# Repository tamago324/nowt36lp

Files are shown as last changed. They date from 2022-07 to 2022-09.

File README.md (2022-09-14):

# nowt36lp

horizon プラグインを使ってボトムプレートとトッププレートを生成した

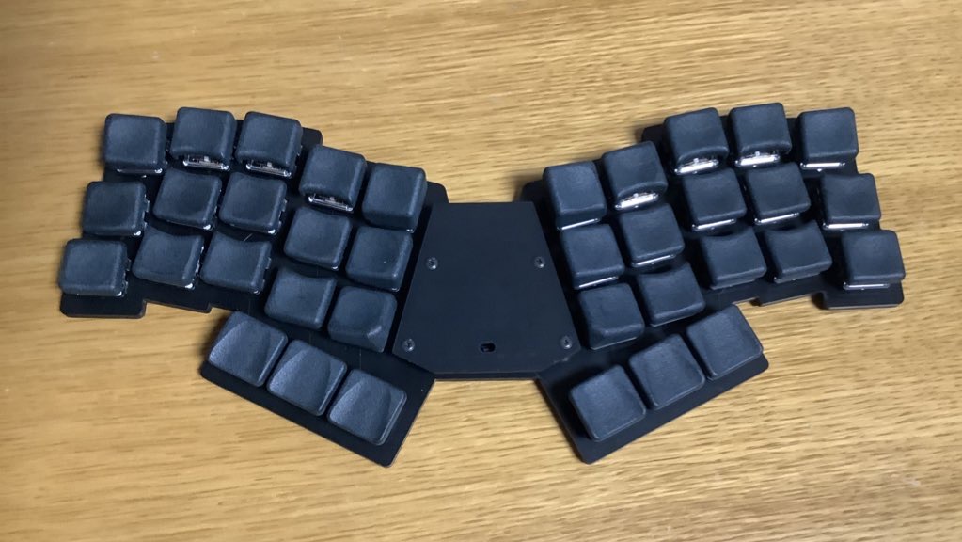
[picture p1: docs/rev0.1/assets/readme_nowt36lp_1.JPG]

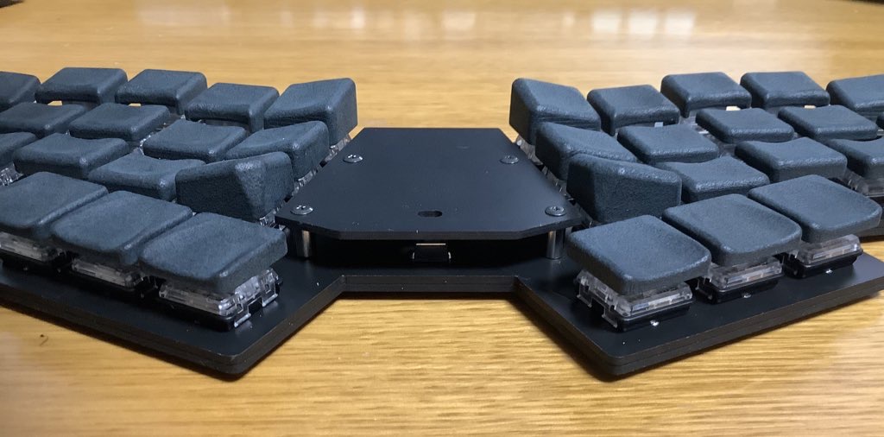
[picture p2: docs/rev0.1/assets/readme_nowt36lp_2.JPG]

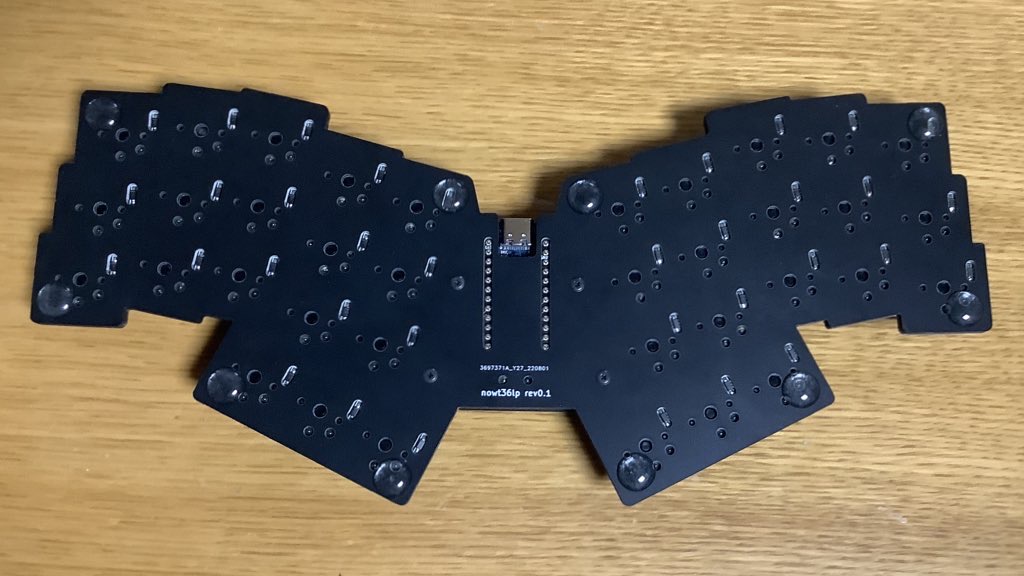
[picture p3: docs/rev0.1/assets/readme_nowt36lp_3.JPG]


## LICENSE

<br />この 作品 は <a rel="license" href="http://creativecommons.org/licenses/by/4.0/">クリエイティブ・コモンズ 表示 4.0 国際 ライセンス</a>の下に提供されています。

> 帰属—適切なクレジットを表示し、ライセンスへのリンクを提供し、変更が行われたかどうかを示す必要があります。

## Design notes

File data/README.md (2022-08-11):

# nowt36lp

## 発注するためのデータの作り方

1. (horizon プラグイン)[https://github.com/skarrmann/horizon]を KiCAD に入れる
2. `revX` (`rev0.1` や `rev0.2` など) 内の `pcb/nowt36lp.kicad_pcb` を開く
3. horizon プラグインを使って、発注するためのデータを作成する

## horizon プラグインの使い方

### もととなるKiCADのデータの作成方法

ボトムプレートとトッププレートを生成するためのデータはレイヤごとに作成されます

* `F.Adhesive` レイヤ：トッププレートの穴とEdge.Cuts
* `B.Adhesive` レイヤ：ボトムプレートの穴とEdge.Cuts

### horizon プラグインを使用して、ボトムプレートとトッププレートのデータを生成する

PCBエディタを開き、ツール > 外部プラグイン > Horizon Board Productor を実行する。

正しく実行できた場合、`data/` ディレクトリに `temp` と `gerbers` が生成される。

`temp` は KiCAD プロジェクトで、`gerbers` は JLCPCB (のみ？) に発注できるデータ。

`temp` を修正し、ガーバーファイルを生成して、発注することも可能

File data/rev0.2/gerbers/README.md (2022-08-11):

rev0.2 の発注用

2022/08/12 に発注し、まだ確認していないがおそらく問題ないと思われる

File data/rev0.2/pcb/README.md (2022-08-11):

## 発注するデータの作成方法

horizon のプラグインを使って、発注するためのデータを作成

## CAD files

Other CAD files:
data/rev0.2/nowt36.FCStd

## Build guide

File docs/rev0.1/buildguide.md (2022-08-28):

# nowt36lp ビルドガイド

nowt36lp rev0.1 のビルドガイドです。

<details><summary>目次</summary><div>

<!-- vim-markdown-toc GFM -->

* [キットに含まれるもの](#キットに含まれるもの)
* [キット以外に必要なもの](#キット以外に必要なもの)
* [組み立て順序の確認](#組み立て順序の確認)
* [組み立て](#組み立て)
  * [1. ファームウェアの書き込み](#1-ファームウェアの書き込み)
    * [Remap で書き込む場合](#remap-で書き込む場合)
  * [2. (オプション) プレートの側面をペンで塗る](#2-オプション-プレートの側面をペンで塗る)
  * [3. ダイオードのはんだ付け](#3-ダイオードのはんだ付け)
  * [4. スイッチのはんだ付け](#4-スイッチのはんだ付け)
  * [5. リセットスイッチのはんだ付け](#5-リセットスイッチのはんだ付け)
  * [6. ボトムプレートを取り付ける](#6-ボトムプレートを取り付ける)
  * [7. ProMicro保護プレートを取り付ける](#7-promicro保護プレートを取り付ける)
  * [8. ゴム足を取り付ける](#8-ゴム足を取り付ける)
  * [9. キーキャップを取り付ける](#9-キーキャップを取り付ける)
  * [10.キーマップを変更する](#10キーマップを変更する)
* [最後に](#最後に)

<!-- vim-markdown-toc -->

</div></details>

## キットに含まれるもの

| No. | 名前 | 数量 | 備考 |
|-----|---|---|---|
| 1 | PCB | 1枚 | メインPCB |
| 2 | ボトムプレート | 1枚 | ボトムアクリルプレート |
| 3 | ProMicro 保護プレート | 1枚 | ProMicro 保護プレート。 |
| 4 | リセットスイッチ | 1個 | タクトスイッチ。<br>[遊舎工房](https://shop.yushakobo.jp/collections/all-keyboard-parts/products/a0800ts-01-1?variant=37665574977697)で購入できます。 |
| 5 | ダイオード | 36個 + 予備 | [遊舎工房](https://shop.yushakobo.jp/collections/all-keyboard-parts/products/a0800di-02-100)で購入できます。 |
| 6 | M2 スペーサー 8mm | 4個 | ProMicro保護プレートとボトムプレートを固定するためのスペーサー。<br>[ヒロスギネット](https://www.hirosugi-net.co.jp/shop/c/c10141012/)で購入できます。 |
| 7 | M2 ねじ 5mm | 8個 | スペーサーを固定するネジ。<br>[モノタロウ](https://www.monotaro.com/p/4307/6774/)で購入できます。 |
| 8 | ゴム足 | 10個 | すべり止め用のゴム足。<br>[Amazon](https://www.amazon.co.jp/gp/product/B01B4COI8W/ref=ppx_yo_dt_b_asin_title_o07_s00?ie=UTF8&psc=1)で購入できます。 |
| 9 | 両面テープ (5mm幅) | - | PCBとボトムプレートを張り合わせるために使用。 <br>[Amazon](https://www.amazon.co.jp/gp/product/B00VFSHS1K/ref=ppx_yo_dt_b_asin_title_o02_s00?ie=UTF8&psc=1)で購入できます。 |

## キット以外に必要なもの

| 名前 | 数量 | 備考 |
|---|---|---|
| キースイッチ | 36個 | choc用のキーキャップ |
| キーキャップ | 36個 | chocスイッチ |
| USBケーブル | 1個  | ProMicroに合ったもの |
| ProMicro | 1個  | - |
| コンスルー or ピンヘッダ | 2枚  | - |

## 組み立て順序の確認

1. ファームウェアの書き込み
2. (オプション) プレートの側面をペンで塗る
3. ダイオードのはんだ付け
4. スイッチのはんだ付け
5. リセットスイッチのはんだ付け
6. ボトムプレートを取り付ける
7. ProMicro保護プレートを取り付ける
8. ゴム足を取り付ける
9. キーキャップを取り付ける
10. キーマップを変更する

## 組み立て

### 1. ファームウェアの書き込み

QMK を使用して、ファームウェアを書き込みます。

ファアームウェアは[こちら](https://github.com/tamago324/qmk_firmware/tree/nowt36/keyboards/tamago324/nowt36lp)

<details><summary>Remap で書き込む場合</summary><div>

#### Remap で書き込む場合

> サリチル酸さんの[記事](https://salicylic-acid3.hatenablog.com/entry/remap-manual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,%E3%83%95%E3%82%A1%E3%83%BC%E3%83%A0%E3%82%A6%E3%82%A7%E3%82%A2%E3%82%92%E6%9B%B8%E3%81%8D%E8%BE%BC%E3%82%80,-%E3%82%AD%E3%83%BC%E3%83%9C%E3%83%BC%E3%83%89%E3%82%AB%E3%82%BF%E3%83%AD%E3%82%B0%E6%A9%9F%E8%83%BD)を参考に手順を記述しています。

https://remap-keys.app/ にアクセスします。 

KEYBOARD CATALOG をクリックします。

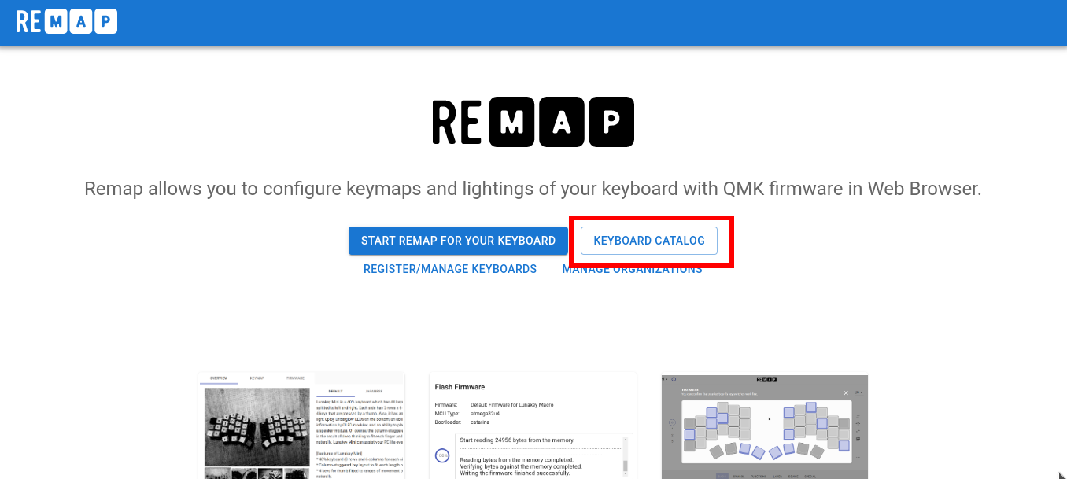
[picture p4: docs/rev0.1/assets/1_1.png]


Keyboard name の入力欄に `nowt36lp` と入力し、Search をクリックし、検索結果の nowt36lp をクリックします。

TODO

FIRMWARE をクリックします。

TODO

FLASH をクリック

TOOD

ダイアログが表示されたら FLASH をクリックします。



remap-keys.app がシリアルポートへの接続を要求しています という表示が出たら、ピンセットでProMicro の`GND`と`RST`を2回素早く押します。



ProMicro が表示されたら、それを選択し、接続ボタンをクリックします。  



少し時間が立つとファームウェアの書き込みが完了します。

TODO

</div></details>

### 2. (オプション) プレートの側面をペンで塗る

PCB と ボトムプレートの側面をペンで塗るときれいに仕上げられます。

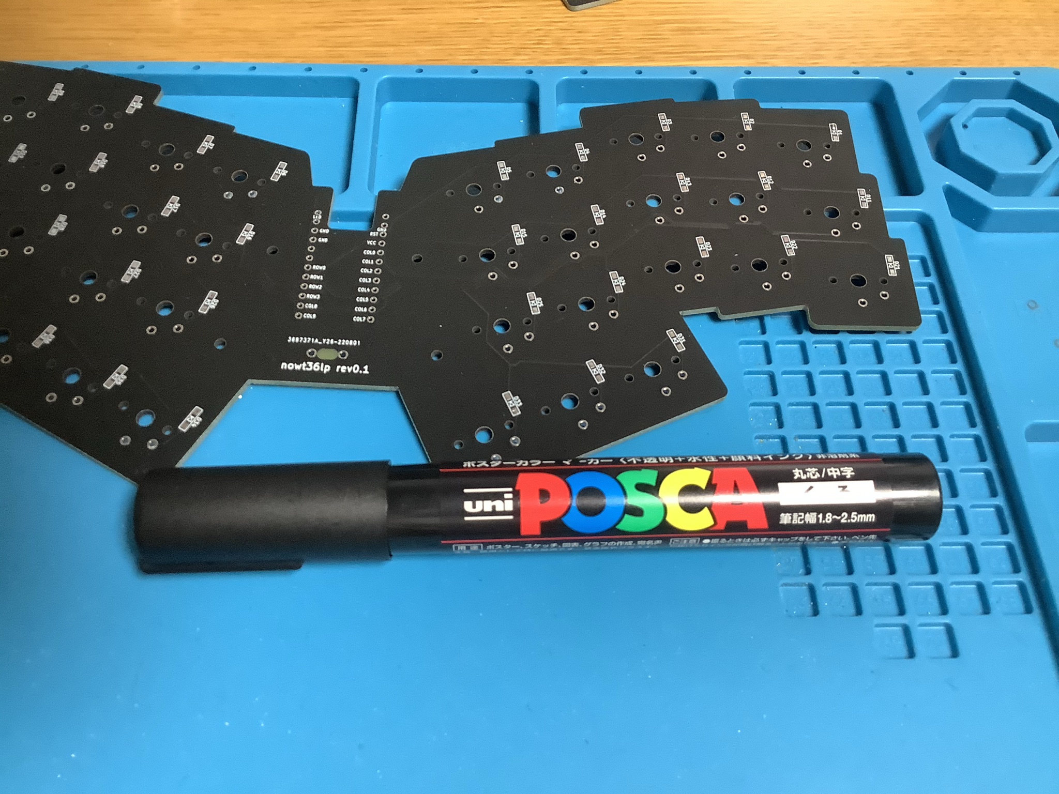
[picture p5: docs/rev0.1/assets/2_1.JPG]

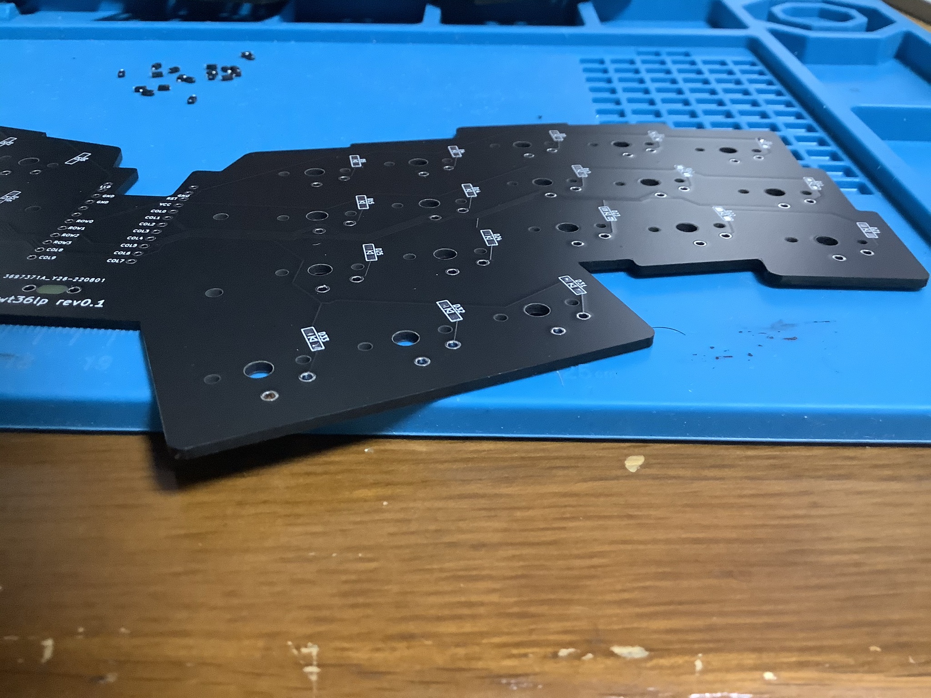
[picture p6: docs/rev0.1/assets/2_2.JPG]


### 3. ダイオードのはんだ付け

PCBの裏にダイオードを36個はんだ付けします。
「PCBのシルクの線」と「ダイオードの線」が一致するようにはんだ付けします。
はんだごての温度は320℃くらいに設定し作業します。

片側に予備ハンダを行い、
ピンセットを使用して、はんだ付けを行い、
もう片方もはんだ付けします。

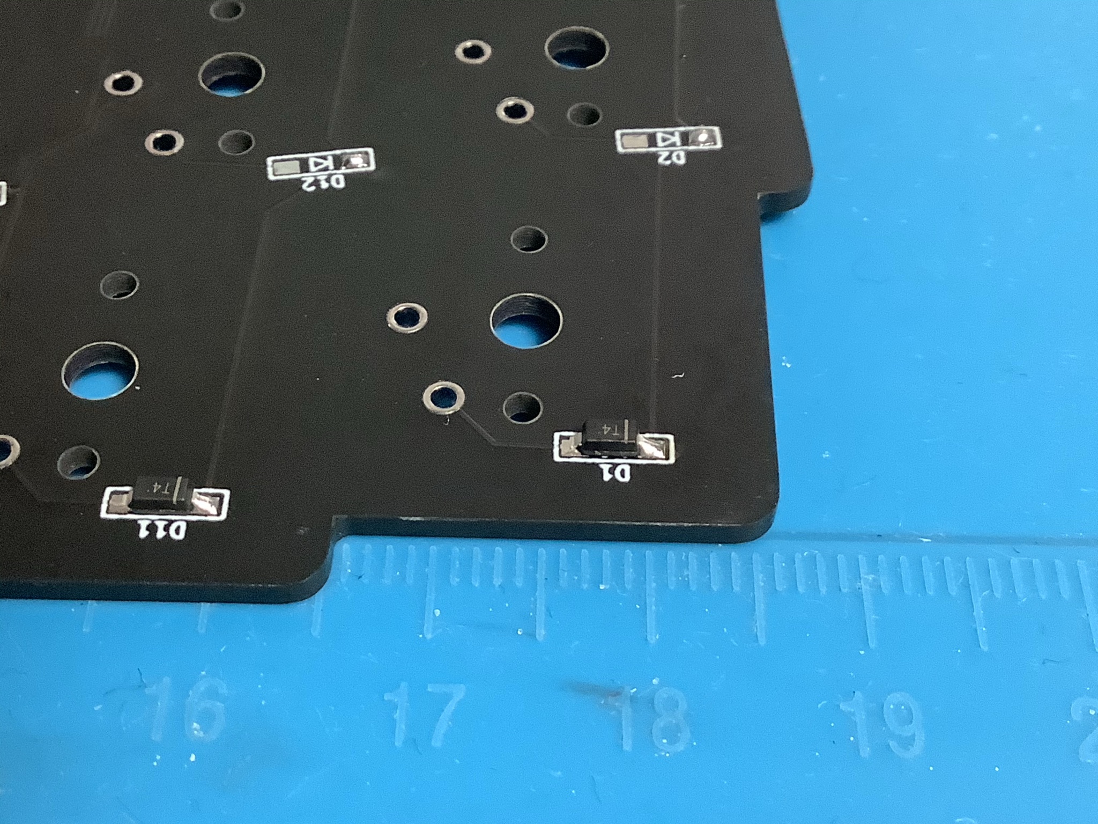
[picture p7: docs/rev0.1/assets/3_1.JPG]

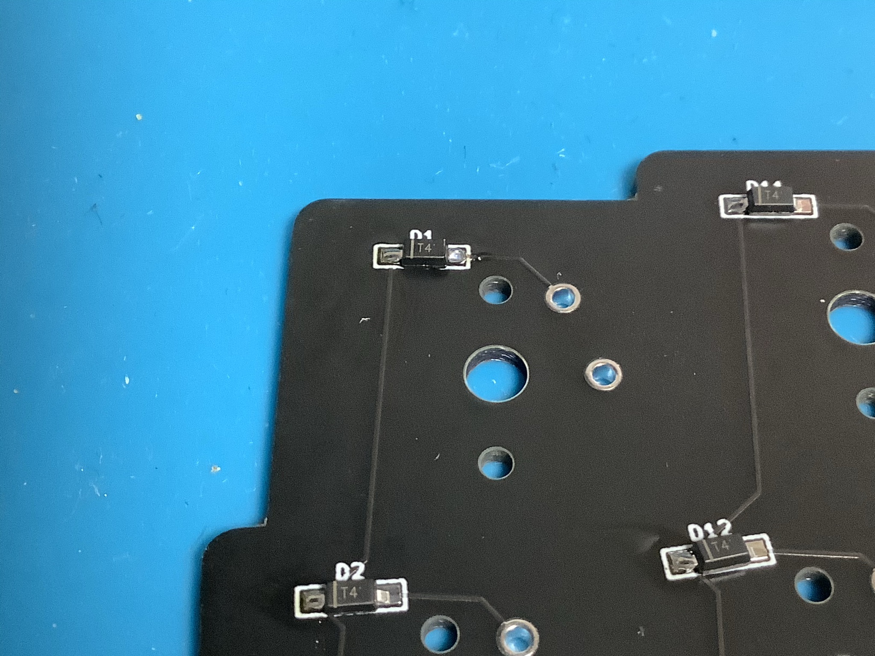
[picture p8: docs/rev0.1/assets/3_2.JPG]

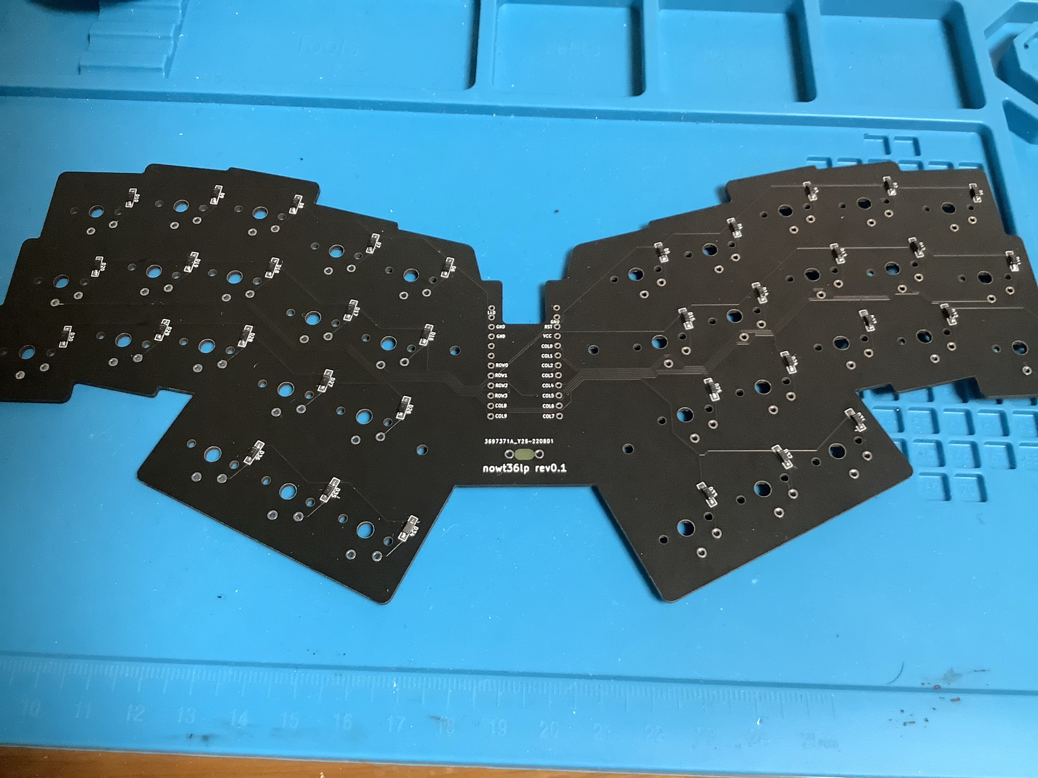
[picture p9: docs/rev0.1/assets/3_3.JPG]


すべてのダイオードのはんだ付けが終わったら、すべてのダイオードが同じ向きになっていることを確認してください。

### 4. スイッチのはんだ付け

PCBの表からスイッチを差し込み、裏からスイッチをはんだ付けします。
はんだごての温度は320℃くらいに設定し作業します。

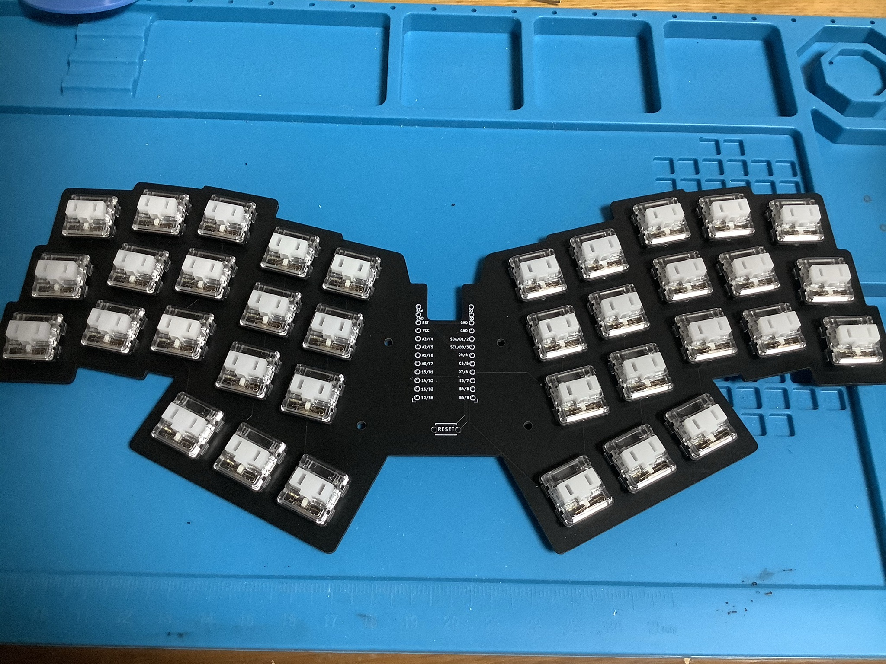
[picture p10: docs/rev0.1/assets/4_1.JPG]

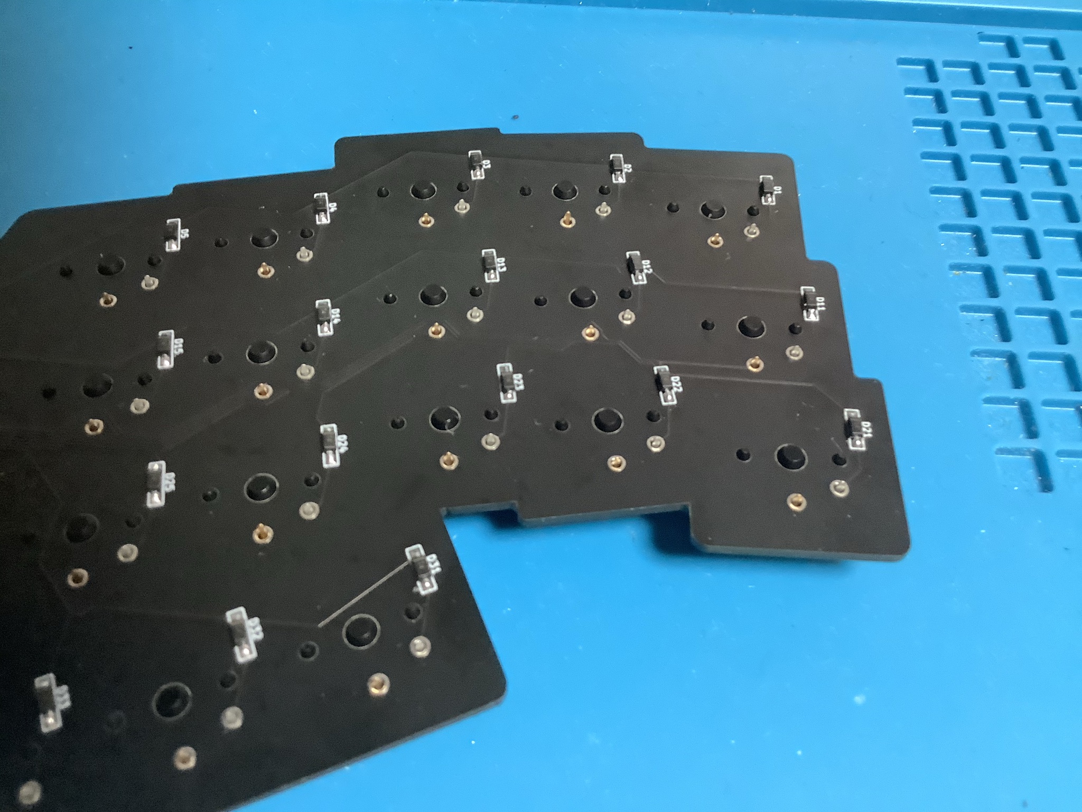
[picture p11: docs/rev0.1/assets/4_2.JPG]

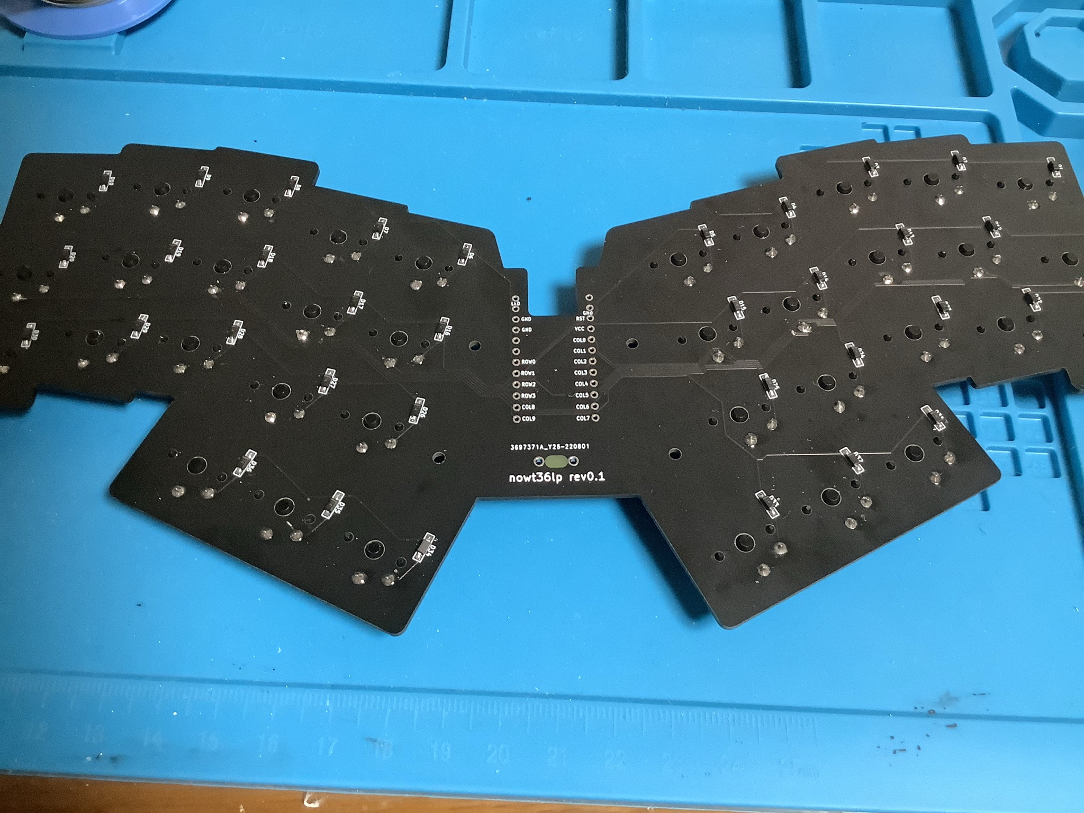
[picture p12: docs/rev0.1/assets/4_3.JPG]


### 5. リセットスイッチのはんだ付け

PCBの表から RESET という文字が隠れるようにリセットスイッチを差し込みます。
PCBの裏に出ている足をはんだ付けします。

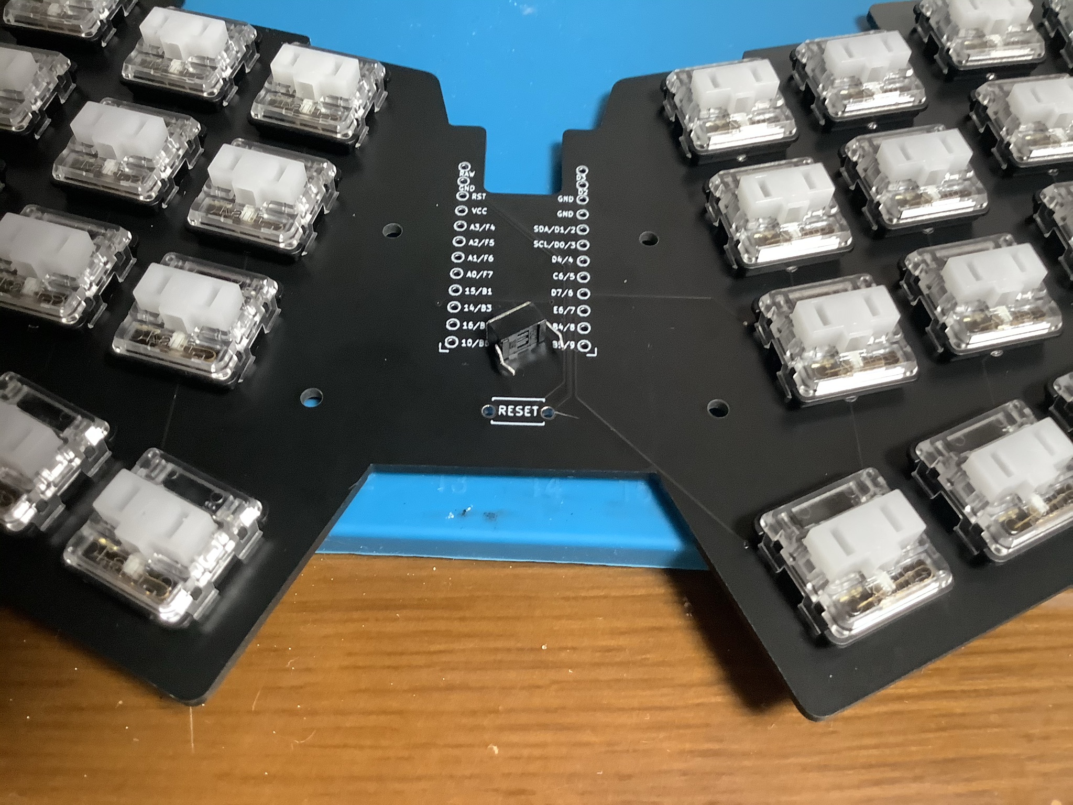
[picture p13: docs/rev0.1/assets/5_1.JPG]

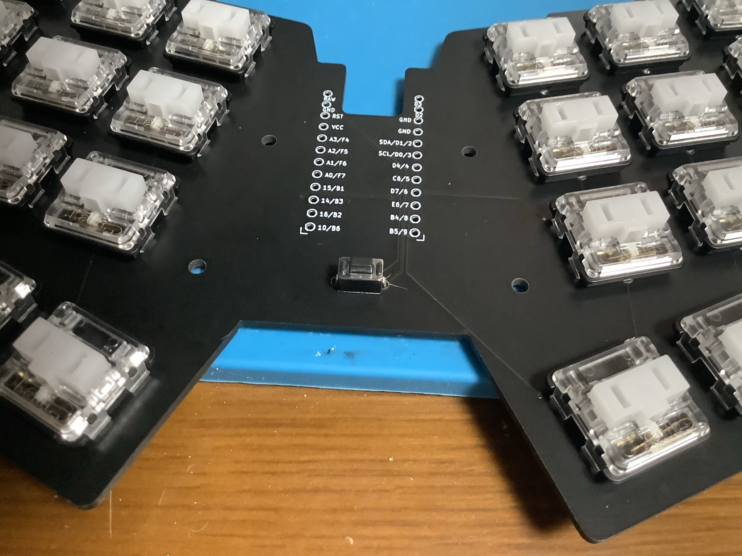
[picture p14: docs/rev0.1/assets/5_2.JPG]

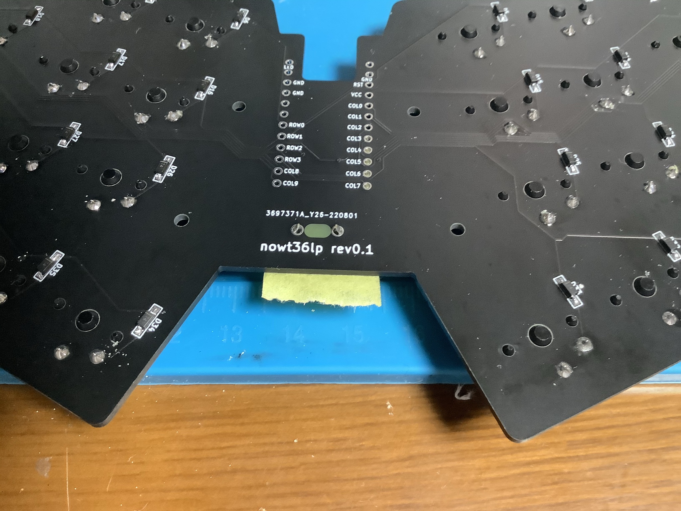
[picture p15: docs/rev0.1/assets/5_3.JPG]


### 6. ボトムプレートを取り付ける

両面テープをPCBに貼り付け、ボトムプレートがずれないように貼り付けます。

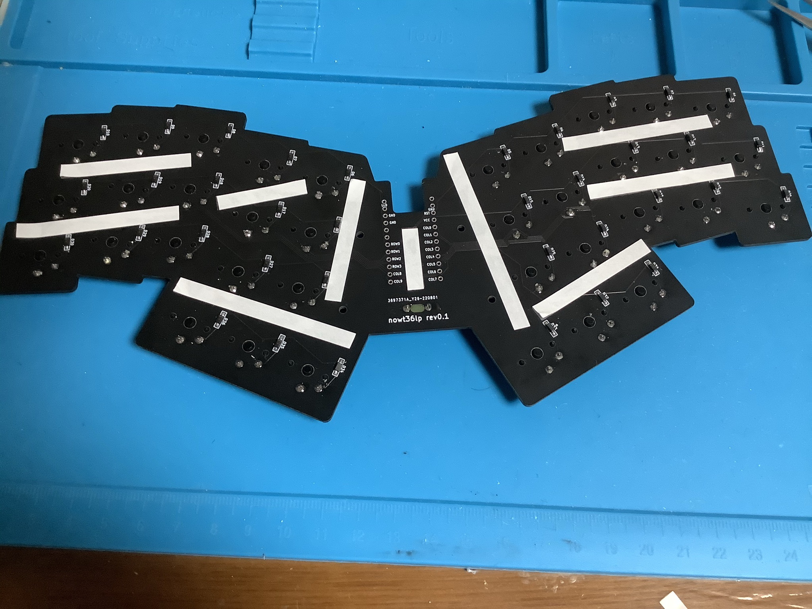
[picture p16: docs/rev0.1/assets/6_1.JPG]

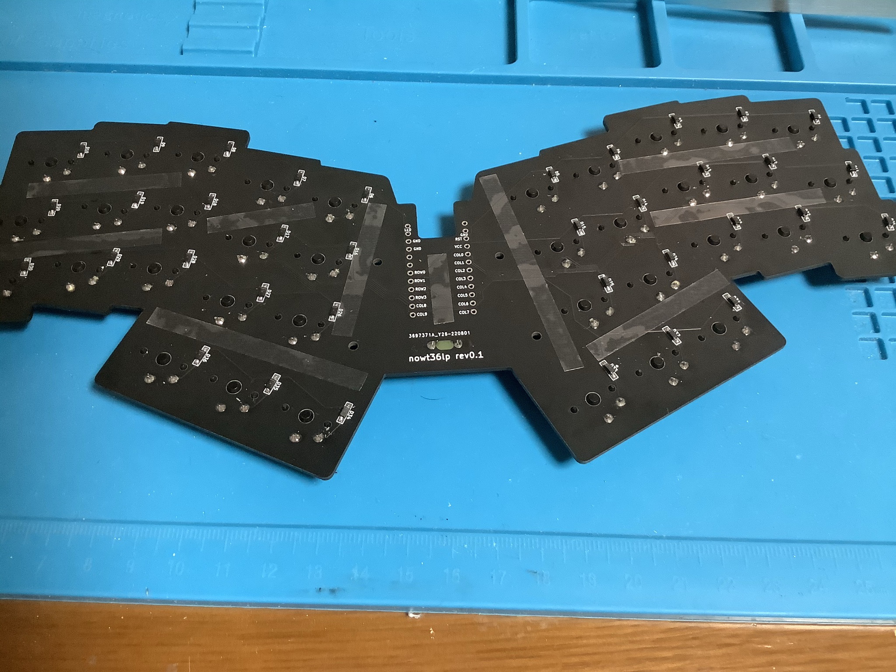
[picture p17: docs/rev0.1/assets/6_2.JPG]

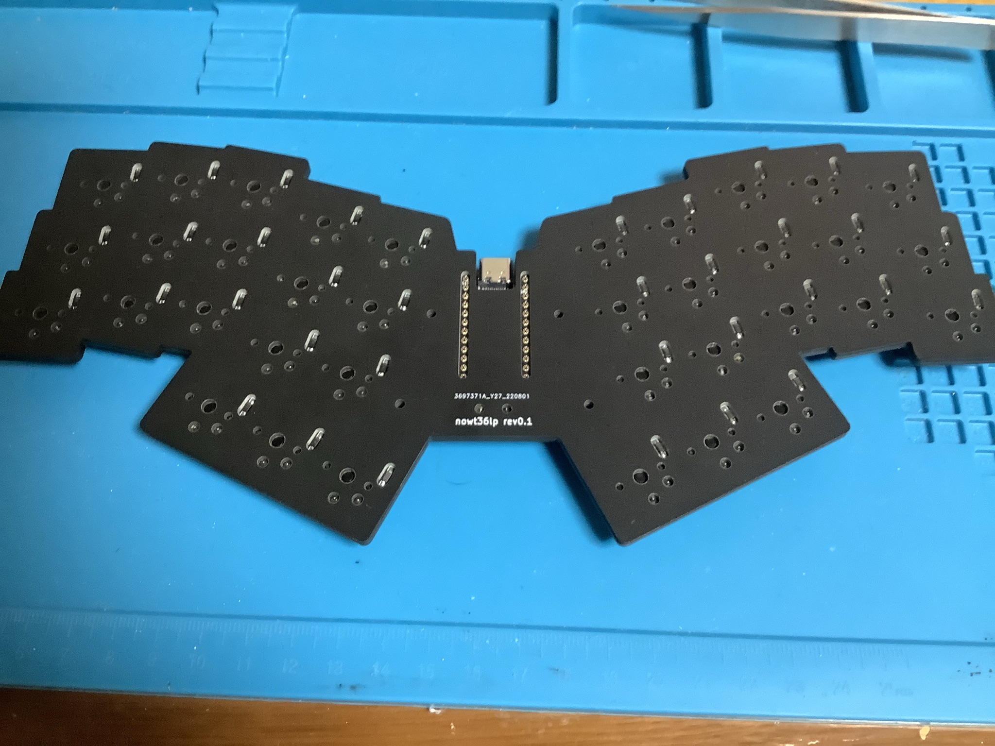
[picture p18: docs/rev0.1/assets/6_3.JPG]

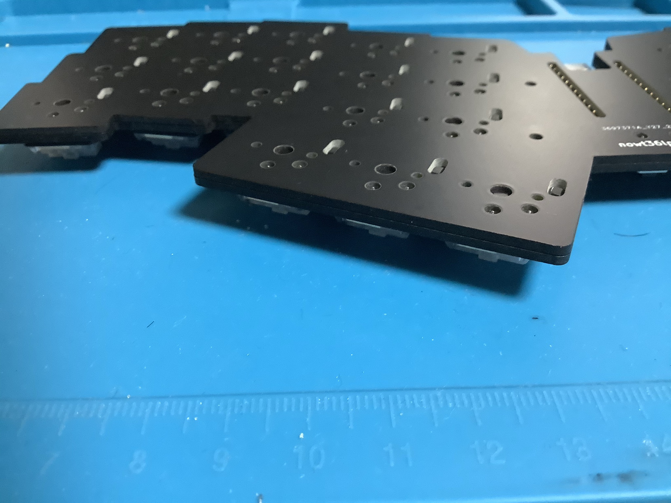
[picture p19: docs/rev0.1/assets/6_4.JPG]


### 7. ProMicro保護プレートを取り付ける

ボトムプレートのうらから、ネジでスペーサーを固定し、ProMicro保護プレートをねじ止めします。

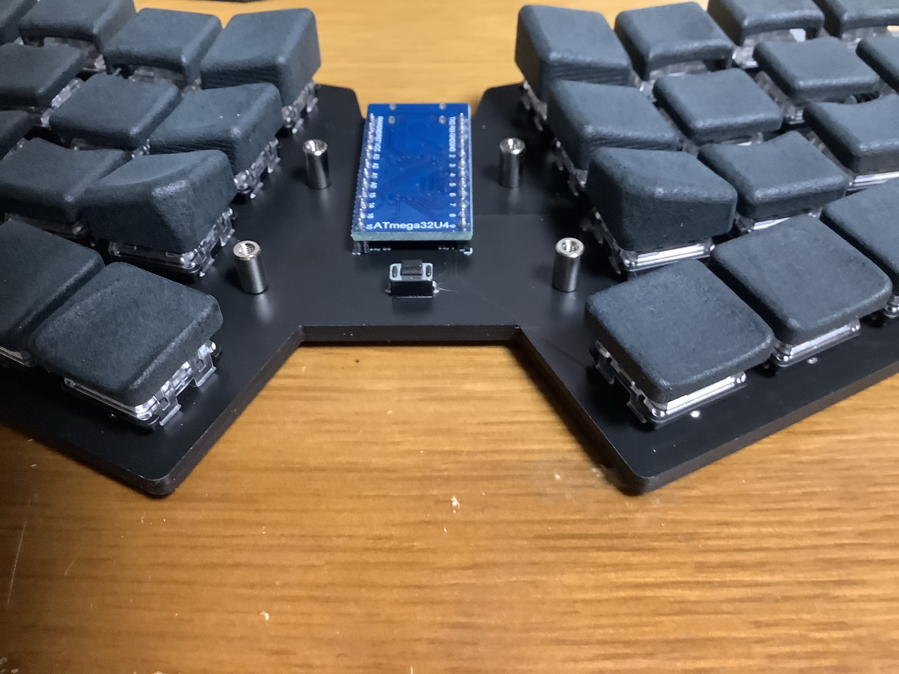
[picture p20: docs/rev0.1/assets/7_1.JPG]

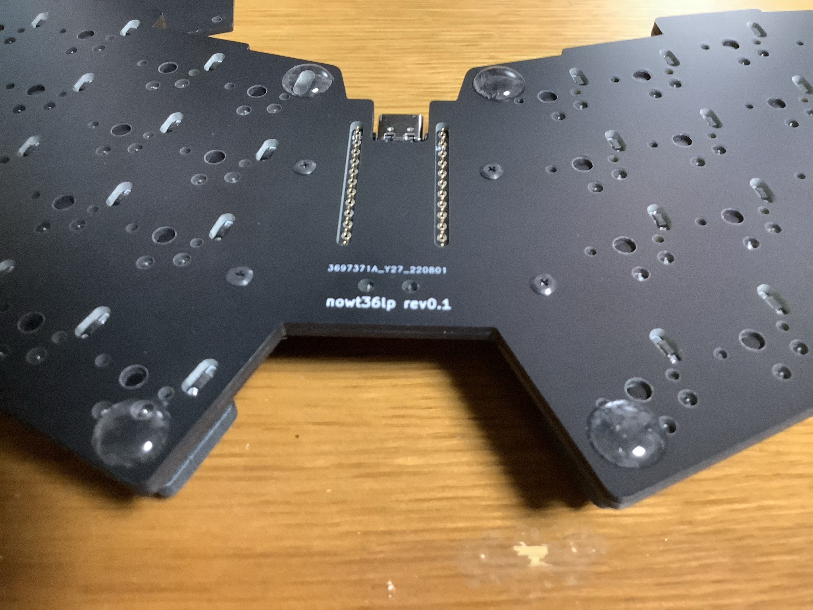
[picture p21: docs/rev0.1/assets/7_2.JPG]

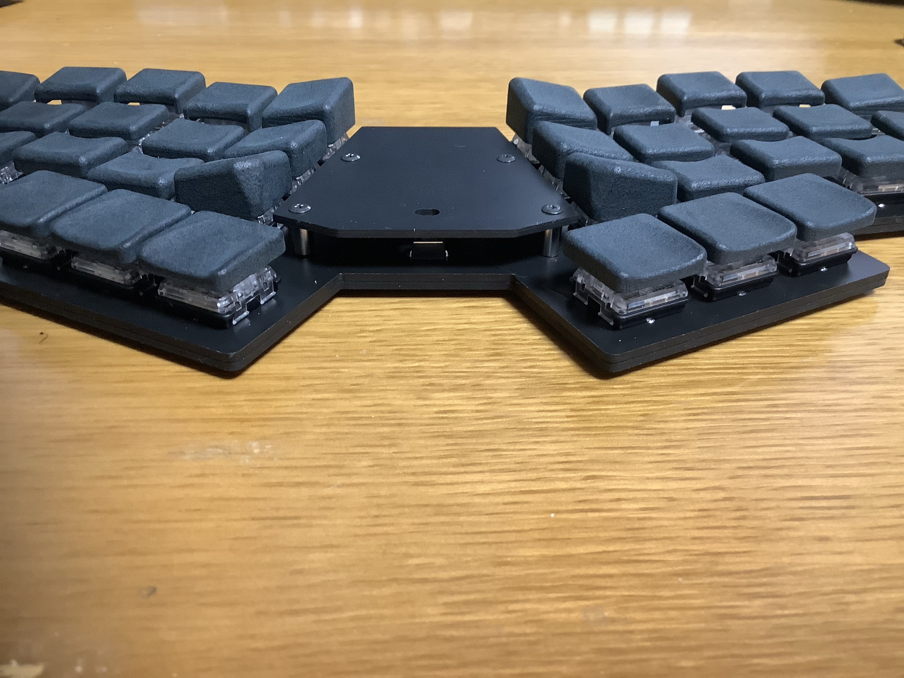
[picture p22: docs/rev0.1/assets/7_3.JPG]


### 8. ゴム足を取り付ける

ボトムプレートの裏にゴム足をつけます。



### 9. キーキャップを取り付ける

キーキャップを取り付けます。



### 10.キーマップを変更する

Remap か QMK を使用してキーマップを変更可能です。

* Remap の場合: キーボードカタログの nowt36lp のページで設定可能です。
* QMK の場合: [tamago324/qmk_firmware](https://github.com/tamago324/qmk_firmware/tree/nowt36) の `nowt36` ブランチの `keyboards/tamago324/nowt36lp` にファームウェアがあります。

## 最後に

完成したキーボードの写真を SNS に投稿していただけるととても嬉しいです！
(ハッシュタグは `#nowt36lp` です。)

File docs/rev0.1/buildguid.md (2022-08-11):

# nowt36lp ビルドガイド

nowt36lp rev0.1 のビルドガイドです。

<details><summary>目次</summary><div>

<!-- vim-markdown-toc GFM -->

* [キットに含まれるもの](#キットに含まれるもの)
* [キット以外に必要なもの](#キット以外に必要なもの)
* [組み立て順序の確認](#組み立て順序の確認)
* [組み立て](#組み立て)
  * [1. ファームウェアの書き込み](#1-ファームウェアの書き込み)
  * [2. (オプション) プレートの側面をペンで塗る](#2-オプション-プレートの側面をペンで塗る)
  * [3. ダイオードのはんだ付け](#3-ダイオードのはんだ付け)
  * [4. スイッチのはんだ付け](#4-スイッチのはんだ付け)
  * [5. リセットスイッチのはんだ付け](#5-リセットスイッチのはんだ付け)
  * [6. ボトムプレートを取り付ける](#6-ボトムプレートを取り付ける)
  * [7. ProMicro保護プレートを取り付ける](#7-promicro保護プレートを取り付ける)
  * [8. ゴム足を取り付ける](#8-ゴム足を取り付ける)
  * [9. キーキャップを取り付ける](#9-キーキャップを取り付ける)
* [最後に](#最後に)

<!-- vim-markdown-toc -->

</div></details>

## キットに含まれるもの

| No. | 名前 | 数量 | 備考 |
|-----|---|---|---|
| 1 | PCB | 1枚  | メインPCB |
| 2 | ボトムプレート | 1枚  | ボトムアクリルプレート |
| 3 | ProMicro 保護プレート | 1枚  | ProMicro 保護プレート。 |
| 4 | リセットスイッチ | 1個  | タクトスイッチ。<br>[遊舎工房](https://shop.yushakobo.jp/collections/all-keyboard-parts/products/a0800ts-01-1?variant=37665574977697)で購入できます。 |
| 5 | M2 スペーサー 7mm | 4個  | ProMicro保護プレートとボトムプレートを固定するためのスペーサー。<br>[ヒロスギネット](https://www.hirosugi-net.co.jp/shop/c/c10141012/)で購入できます。 |
| 6 | M2 ねじ 5mm | 8個  | スペーサーを固定するネジ。<br>[モノタロウ](https://www.monotaro.com/p/4307/6774/)で購入できます。 |
| 7 | ゴム足 | 10個 | すべり止め用のゴム足。<br>[Amazon](https://www.amazon.co.jp/gp/product/B01B4COI8W/ref=ppx_yo_dt_b_asin_title_o07_s00?ie=UTF8&psc=1)で購入できます。 |
| 8 | 両面テープ (5mm幅) | - | PCBとボトムプレートを張り合わせるために使用。 <br>[Amazon](https://www.amazon.co.jp/gp/product/B00VFSHS1K/ref=ppx_yo_dt_b_asin_title_o02_s00?ie=UTF8&psc=1)で購入できます。 |

## キット以外に必要なもの

| 名前 | 数量 | 備考 |
|---|---|---|
| キースイッチ | 36個 | choc用のキーキャップ |
| キーキャップ | 36個 | chocスイッチ |
| USBケーブル | 1個  | ProMicroに合ったもの |
| ProMicro | 1個  | - |
| コンスルー or ピンヘッダ | 2枚  | - |

## 組み立て順序の確認

1. ファームウェアの書き込み
2. (オプション) プレートの側面をペンで塗る
3. ダイオードのはんだ付け
4. スイッチのはんだ付け
5. リセットスイッチのはんだ付け
6. ボトムプレートを取り付ける
7. ProMicro保護プレートを取り付ける
8. ゴム足を取り付ける
9. キーキャップを取り付ける

## 組み立て

### 1. ファームウェアの書き込み

[QMK](https://github.com/tamago324/qmk_firmware/tree/nowt36/keyboards/nowt36) を使用して、ファームウェアを書き込みます。

> TODO: REMAP での書き込みに対応する

### 2. (オプション) プレートの側面をペンで塗る

PCB と ボトムプレートの側面をペンで塗るときれいに仕上げられます。




### 3. ダイオードのはんだ付け

PCBの裏にダイオードを36個はんだ付けします。
「PCBのシルクの線」と「ダイオードの線」が一致するようにはんだ付けします。
はんだごての温度は320℃くらいに設定し作業します。

片側に予備ハンダを行い、
ピンセットを使用して、はんだ付けを行い、
もう片方もはんだ付けします。





すべてのダイオードのはんだ付けが終わったら、すべてのダイオードが同じ向きになっていることを確認してください。

### 4. スイッチのはんだ付け

PCBの表からスイッチを差し込み、裏からスイッチをはんだ付けします。
はんだごての温度は320℃くらいに設定し作業します。





### 5. リセットスイッチのはんだ付け

PCBの表から RESET という文字が隠れるようにリセットスイッチを差し込みます。
PCBの裏に出ている足をはんだ付けします。





### 6. ボトムプレートを取り付ける

両面テープをPCBに貼り付け、ボトムプレートがずれないように貼り付けます。






### 7. ProMicro保護プレートを取り付ける

ボトムプレートのうらから、ネジでスペーサーを固定し、ProMicro保護プレートをねじ止めします。





### 8. ゴム足を取り付ける

ボトムプレートの裏にゴム足をつけます。



### 9. キーキャップを取り付ける

キーキャップを取り付けます。



## 最後に

完成したキーボードの写真を SNS に投稿していただけるととても嬉しいです！
(ハッシュタグは `#nowt36lp` です。)

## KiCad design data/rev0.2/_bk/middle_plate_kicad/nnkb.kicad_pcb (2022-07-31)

Board: 2 copper layers, 48 parts (0 on the bottom side), 10 nets, no tracks yet.

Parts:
D37, D38, D39, D40, D41, D42, D43, D44, D45, D46: WS2812B; LED_WS2812B_PLCC4_5.0x5.0mm_P3.2mm_middle
SW1, SW2, SW3, SW4, SW5, SW6, SW7, SW8, SW9, SW10, SW11, SW12, SW13, SW14, SW15, SW16, SW17, SW18, SW19, SW20, SW21, SW22, SW23, SW24, SW25, SW26, SW27, SW28, SW29, SW30, SW31, SW32, SW33, SW34, SW35, SW36: SW_PUSH; CherryMX_Hotswap_middle
SW37: RESET_SWITCH; ResetSW_1side_back_middle
U1: ProMicro; ProMicro_v3.5_mods_middle

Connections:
col0: SW1.1, SW11.1, SW21.1
col1: SW2.1, SW12.1, SW22.1
col2: SW3.1, SW13.1, SW23.1, SW31.1
col3: SW4.1, SW14.1, SW24.1, SW32.1
col4: SW5.1, SW15.1, SW25.1, SW33.1
col5: SW6.1, SW16.1, SW26.1, SW34.1
col6: SW7.1, SW17.1, SW27.1, SW35.1
col7: SW8.1, SW18.1, SW28.1, SW36.1
col8: SW9.1, SW19.1, SW29.1
col9: SW10.1, SW20.1, SW30.1

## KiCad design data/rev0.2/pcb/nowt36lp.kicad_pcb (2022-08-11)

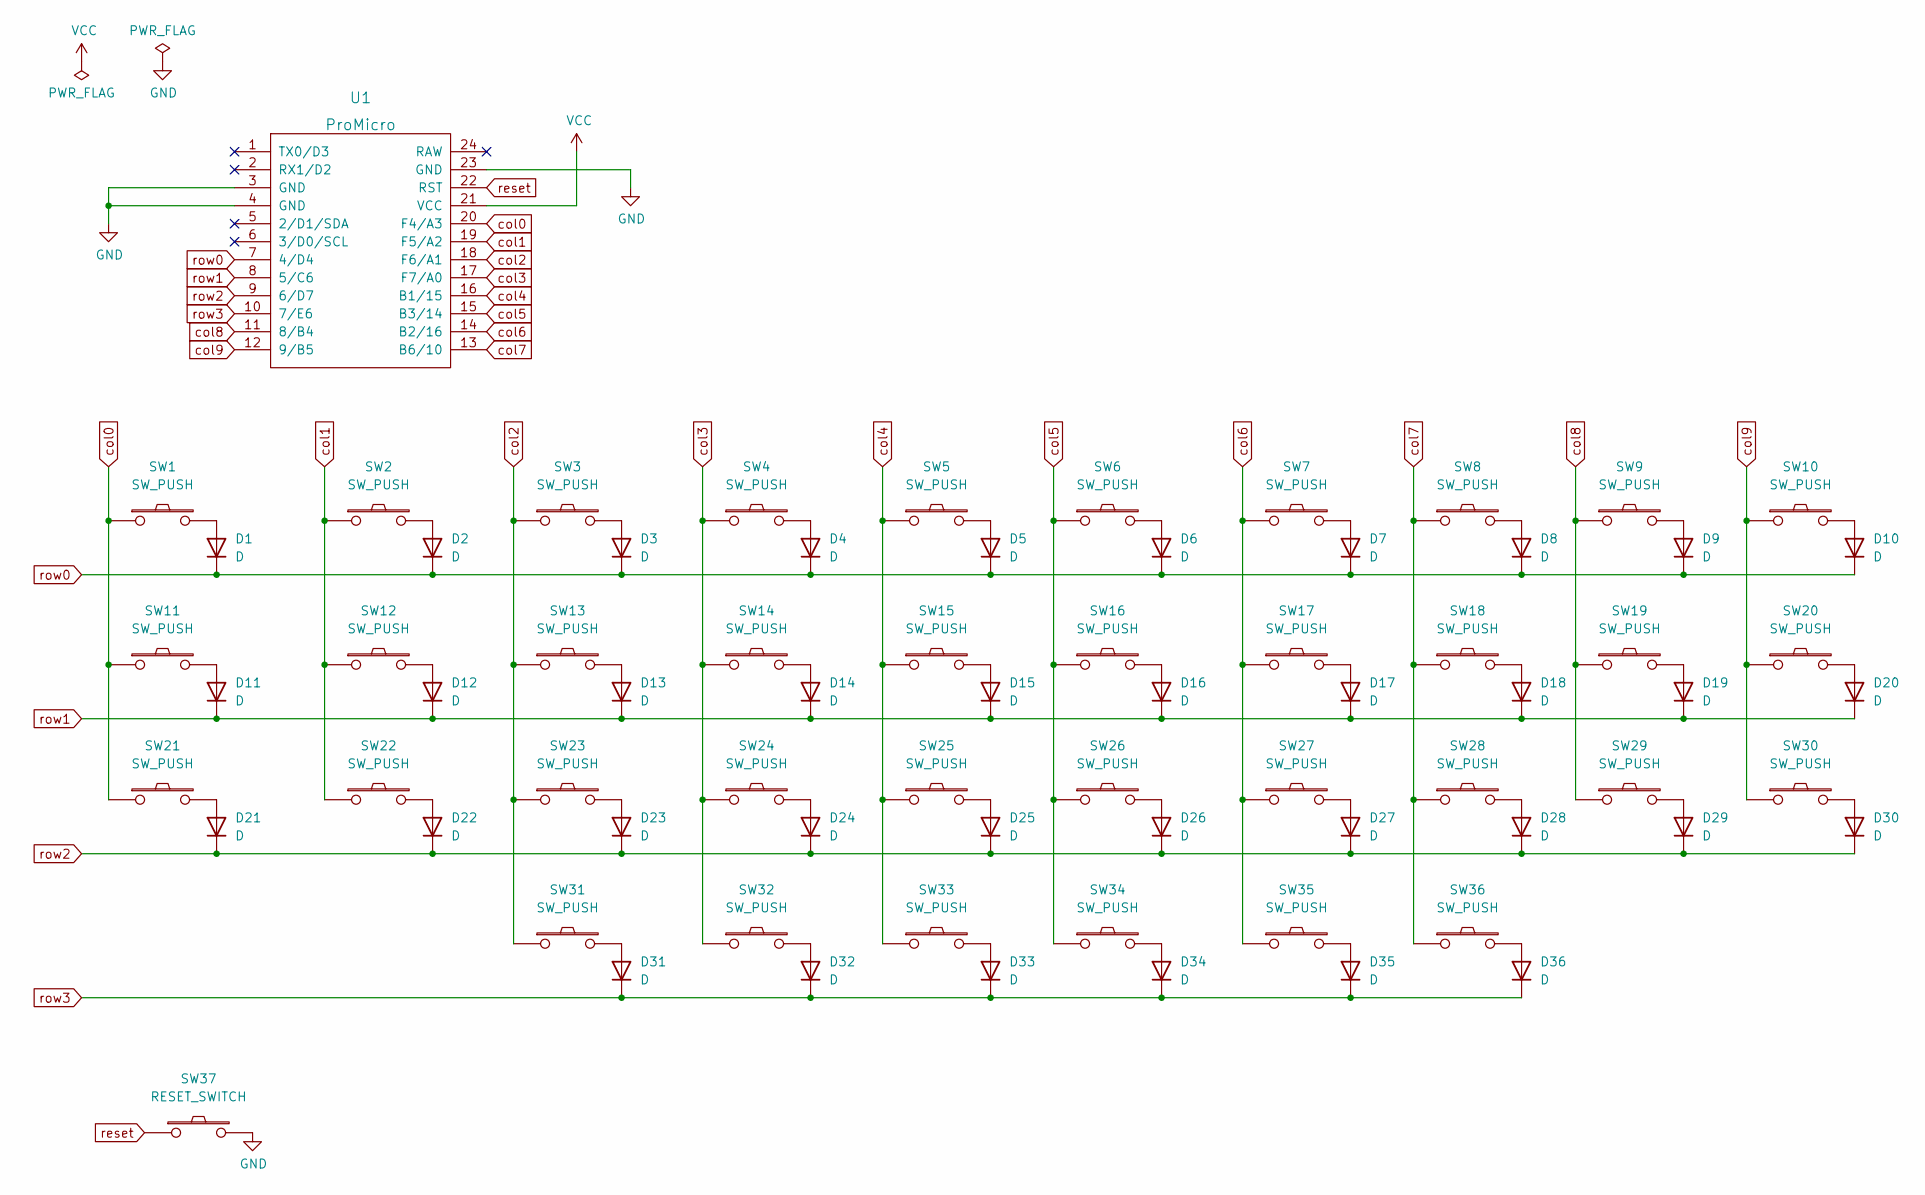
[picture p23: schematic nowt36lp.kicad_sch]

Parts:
D1, D2, D3, D4, D5, D6, D7, D8, D9, D10, D11, D12, D13, D14, D15, D16, D17, D18, D19, D20, D21, D22, D23, D24, D25, D26, D27, D28, D29, D30, D31, D32, D33, D34, D35, D36: D; Diode_SMD
SW1, SW2, SW3, SW4, SW5, SW6, SW7, SW8, SW9, SW10, SW11, SW12, SW13, SW14, SW15, SW16, SW17, SW18, SW19, SW20, SW21, SW22, SW23, SW24, SW25, SW26, SW27, SW28, SW29, SW30, SW31, SW32, SW33, SW34, SW35, SW36: SW_PUSH; SW_Choc
SW37: RESET_SWITCH; TVAF17-WFC-R_mods
U1: ProMicro; ProMicro_v3.5_mods

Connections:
GND: SW37.2, U1.3 (GND), U1.4 (GND), U1.23 (GND)
unnamed: D1.2 (A), SW1.2
unnamed: D2.2 (A), SW2.2
unnamed: D3.2 (A), SW3.2
unnamed: D4.2 (A), SW4.2
unnamed: D5.2 (A), SW5.2
unnamed: D6.2 (A), SW6.2
unnamed: D7.2 (A), SW7.2
unnamed: D8.2 (A), SW8.2
unnamed: D9.2 (A), SW9.2
unnamed: D10.2 (A), SW10.2
unnamed: D11.2 (A), SW11.2
unnamed: D12.2 (A), SW12.2
unnamed: D13.2 (A), SW13.2
unnamed: D14.2 (A), SW14.2
unnamed: D15.2 (A), SW15.2
unnamed: D16.2 (A), SW16.2
unnamed: D17.2 (A), SW17.2
unnamed: D18.2 (A), SW18.2
unnamed: D19.2 (A), SW19.2
unnamed: D20.2 (A), SW20.2
unnamed: D21.2 (A), SW21.2
unnamed: D22.2 (A), SW22.2
unnamed: D23.2 (A), SW23.2
unnamed: D24.2 (A), SW24.2
unnamed: D25.2 (A), SW25.2
unnamed: D26.2 (A), SW26.2
unnamed: D27.2 (A), SW27.2
unnamed: D28.2 (A), SW28.2
unnamed: D29.2 (A), SW29.2
unnamed: D30.2 (A), SW30.2
unnamed: D31.2 (A), SW31.2
unnamed: D32.2 (A), SW32.2
unnamed: D33.2 (A), SW33.2
unnamed: D34.2 (A), SW34.2
unnamed: D35.2 (A), SW35.2
unnamed: D36.2 (A), SW36.2
VCC: U1.21 (VCC)
col0: SW1.1, SW11.1, SW21.1, U1.20 (F4/A3)
col1: SW2.1, SW12.1, SW22.1, U1.19 (F5/A2)
col2: SW3.1, SW13.1, SW23.1, SW31.1, U1.18 (F6/A1)
col3: SW4.1, SW14.1, SW24.1, SW32.1, U1.17 (F7/A0)
col4: SW5.1, SW15.1, SW25.1, SW33.1, U1.16 (B1/15)
col5: SW6.1, SW16.1, SW26.1, SW34.1, U1.15 (B3/14)
col6: SW7.1, SW17.1, SW27.1, SW35.1, U1.14 (B2/16)
col7: SW8.1, SW18.1, SW28.1, SW36.1, U1.13 (B6/10)
col8: SW9.1, SW19.1, SW29.1, U1.11 (8/B4)
col9: SW10.1, SW20.1, SW30.1, U1.12 (9/B5)
reset: SW37.1, U1.22 (RST)
row0: D1.1 (K), D2.1 (K), D3.1 (K), D4.1 (K), D5.1 (K), D6.1 (K), D7.1 (K), D8.1 (K), D9.1 (K), D10.1 (K), U1.7 (4/D4)
row1: D11.1 (K), D12.1 (K), D13.1 (K), D14.1 (K), D15.1 (K), D16.1 (K), D17.1 (K), D18.1 (K), D19.1 (K), D20.1 (K), U1.8 (5/C6)
row2: D21.1 (K), D22.1 (K), D23.1 (K), D24.1 (K), D25.1 (K), D26.1 (K), D27.1 (K), D28.1 (K), D29.1 (K), D30.1 (K), U1.9 (6/D7)
row3: D31.1 (K), D32.1 (K), D33.1 (K), D34.1 (K), D35.1 (K), D36.1 (K), U1.10 (7/E6)

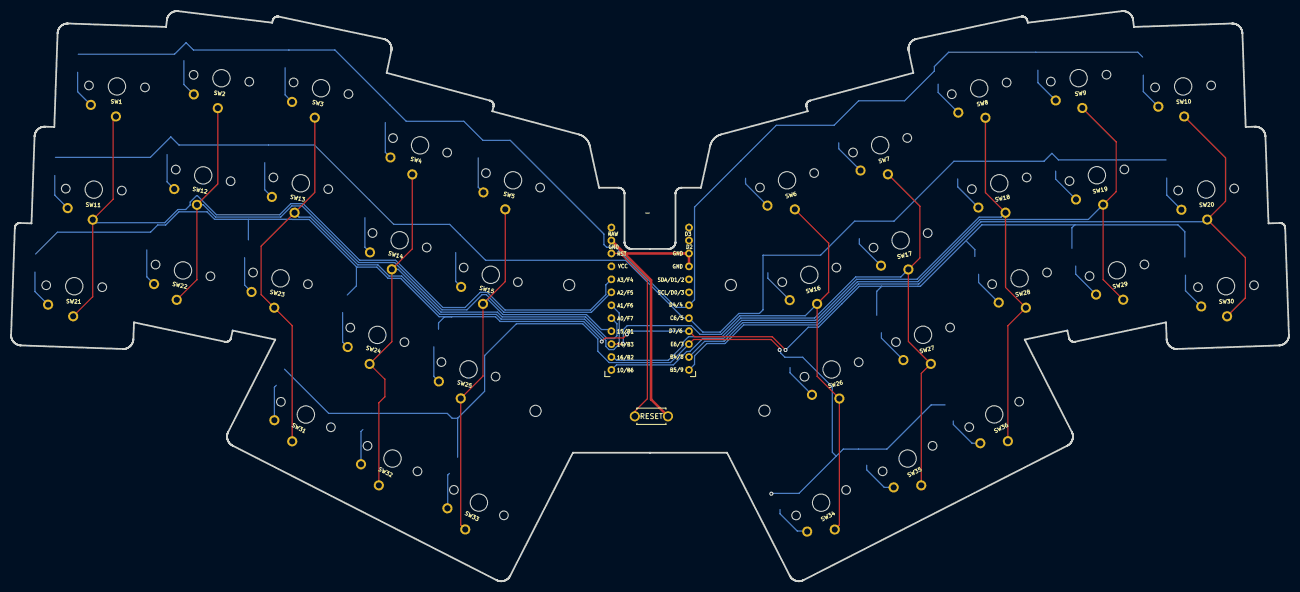
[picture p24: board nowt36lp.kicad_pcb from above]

Board: 2 copper layers, 250.7 x 111.8 mm, 78 parts (0 on the bottom side), 52 nets.

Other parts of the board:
Ref**: Val**; spacer_m2_2.2mm
Ref**#2, Ref**#3, Ref**#4: Val**; spacer_m2_2.2mm

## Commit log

2022-08-11 ビルドガイドを追加
    [nnkb.kicad_pcb, nnkb.kicad_sch, nowt36.FCStd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]
2022-08-11 ビルドガイドの配置を変更
2022-08-11 画像を追加
2022-08-11 ビルドガイドのパスを修正
2022-08-11 前のビルドガイドを削除
2022-08-11 部品の説明に改行を追加
2022-08-11 ファームウェアのパスを修正
2022-08-11 いらないデータを削除
2022-08-11 ビルドガイド更新
2022-08-11 horizonプラグインの使い方を追加
    [nnkb.kicad_pcb, nnkb.kicad_sch, nowt36.FCStd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]
2022-09-03 ライセンスを CC BY に変更
2022-09-14 画像の追加

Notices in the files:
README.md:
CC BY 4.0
